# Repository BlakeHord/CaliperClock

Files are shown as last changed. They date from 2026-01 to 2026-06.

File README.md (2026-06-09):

# Caliper Clock

A low-power digital clock that uses the LCD salvaged from a cheap digital
caliper. The custom board drops into the caliper body, drives its 4-mux glass
directly, and is designed to operate for >1 year off a single 1.5V LR44 button cell.

Three major hardware revisions live in this repo.

## Revisions

| Dir | Board | Status |
|-----|---|---|
| [`Caliper_Clock_V1/`](Caliper_Clock_V1/) | ATtiny1616 + HT1621B LCD driver + RV-3028 RTC (incl. a test board) | original design |
| [`Caliper_Clock_V2/`](Caliper_Clock_V2/) | revised V1-class board **+ the working V2 firmware** | source of truth for the caliper LCD segment map & set-time UX. Battery depleted in days due to constant boost switching (wrong component choice) |
| [`Caliper_Clock_V3/`](Caliper_Clock_V3/) | **active redesign** around an **MSP430FR4133** (FRAM, integrated LCD_E + RTC, no HT1621) | hardware-verified, firmware **v1.0** running on the custom board |

**Active work is V3.** Its firmware ports the V2 segment map and time-setting
state machine onto the MSP430, displaying time on the real caliper glass via the
chip's built-in LCD controller and keeping time with the integrated RTC.

## V3 at a glance

- **MCU:** MSP430FR4133 (LCD_E drives the 4-mux caliper glass directly).
- **Power:** boosts a 1.5 V LR44 cell to 3.0 V (TPS61099); sleeps in LPM3 with
  the always-on LCD, targeting ~µA average for >year battery life.
- **Firmware:** `Caliper_Clock_V3/firmware/` — MSP430-GCC + `mspdebug`. The
  default build is the v1.0 product (full clock + buttons on the caliper glass);
  numbered diagnostic builds remain for bring-up. See its
  [README](Caliper_Clock_V3/firmware/README.md).
- **Hardware:** KiCad design, datasheets, and gerbers under `Caliper_Clock_V3/`.

```sh
cd Caliper_Clock_V3/firmware
make            # build v1.0 (the product)
make flash      # build + flash via the LaunchPad's eZ-FET (Spy-Bi-Wire)
```

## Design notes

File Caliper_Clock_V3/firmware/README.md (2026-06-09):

# Caliper Clock V3 Firmware

Firmware for the **MSP430FR4133IPM**-based Caliper Clock V3. Developed and tested
on an **MSP-EXP430FR4133 LaunchPad** while the custom boards are at the fab.

Toolchain: **MSP430-GCC** (compiler) + **mspdebug** with the **tilib** backend
(flashing over Spy-Bi-Wire via the LaunchPad's onboard eZ-FET). No CCS.

> Target platform for this setup: **macOS on Apple Silicon**. The clean path is
> MacPorts, because the `tilib` backend needs TI's proprietary `libmsp430.dylib`,
> which Homebrew core does not package. (Note: no live GDB on Apple Silicon —
> TI's debug-stack GDB path is x86_64 only. `mspdebug` still flashes fine.)

## Layout

```
firmware/
├── Makefile        # build / flash / debug / clean
├── src/            # .c sources (main.c = Task 1 blink stub for now)
├── inc/            # .h headers
├── build/          # object files        (git-ignored)
└── bin/            # firmware.elf output (git-ignored)
```

## One-time toolchain install (MacPorts)

1. Install MacPorts if you don't have it: https://www.macports.org/install.php
2. Install the compiler + flasher (pulls in support files, binutils, and the
   custom `libmsp430` port that provides the TI debug-stack dylib):

   ```sh
   sudo port install msp430-elf-gcc mspdebug
   ```

3. Verify the compiler is on PATH:

   ```sh
   msp430-elf-gcc --version
   ```

4. **Locate the device support files** (headers + linker script). The build
   needs `msp430fr4133.h` and `msp430fr4133.ld`:

   ```sh
   port contents msp430-gcc-support-files | grep -E 'msp430fr4133\.(h|ld)'
   ```

   - If they sit on the compiler's default search path, you're done.
   - Otherwise set `SUPPORT_DIR` to the directory containing them, either by
     editing the `Makefile` or per-invocation: `make SUPPORT_DIR=/path/to/include`.

## Build

```sh
make                 # builds the v1.0 PRODUCT (BRINGUP=7) -> bin/firmware.elf
make BRINGUP=1       # build a specific diagnostic instead (see below)
make clean           # removes build/ and bin/
```

The **default build is the product**: `BRINGUP=7`, the full clock on the caliper
glass (timekeeping + display + buttons), versioned `FW_VERSION` in the Makefile
(currently **v1.0**). The build prints a banner saying whether it produced the
product or a diagnostic.

`src/main.c` still selects the build at compile time via `BRINGUP`; the numbered
bring-up/diagnostic builds are kept in-tree and reachable with an override (e.g.
`make BRINGUP=3`). The object files don't track that flag, so **`make clean` when
switching `BRINGUP`**.

## Flash & debug (LaunchPad connected via USB)

```sh
make flash               # build + flash the v1.0 PRODUCT (BRINGUP=7)
make BRINGUP=1 flash     # build+flash a specific diagnostic instead
make debug               # interactive mspdebug session
```

The Makefile prefixes mspdebug with `DYLD_LIBRARY_PATH=/opt/local/lib` so `tilib`
can find `libmsp430.dylib`. If flashing fails to find the FET, unplug/replug the
LaunchPad and retry (a known macOS eZ-FET quirk).

## Bring-up sequence

Each step has a flashable test and a concrete "you should see X" so a failure
isolates to the layer just added — instead of debugging a whole clock at once.
Steps 1–6 verify on the LaunchPad; **step 7 is the v1.0 product** — the full
clock on the real caliper glass — and is now the default `make` build (it
requires a V3 board). The ladder is kept for diagnosing a regression to the
layer that introduced it.

| # | Build | What it proves | Pass criterion | Status |
|---|---|---|---|---|
| 1 | `make BRINGUP=1 flash` | Toolchain + flash path + chip alive | LaunchPad LED2 (P4.0) blinks ~1 Hz | ✓ |
| 2 | `make BRINGUP=2 flash` | LCD_E peripheral: 4-mux, charge-pump bias, ACLK, pin mux | LaunchPad glass shows **HELLO** | ✓ |
| 3 | `make BRINGUP=3 flash` (V3) | The V3→caliper SEG/COM map matches the physical glass | Scan test lights each (Lxx,COM) | ✓ (superseded by BRINGUP=14 slow scan) |
| 4 | `make BRINGUP=4 flash` | XT1 32.768 kHz + RTC 1 Hz tick | Time advances; LED2 toggles every 1 s | ✓ |
| 5 | `make BRINGUP=5 flash` | P1.0–1.2 wake from LPM3; 50 ms debounce | Button-to-GND shows MODE/HOUR/MIN | ✓ |
| 6 | `make BRINGUP=6 flash` | Full clock + set-time UI on LaunchPad | Time advances; long-press MODE → set; HOUR/MIN adjust; MODE commits | ✓ |
| 7 | `make flash` (default; V3) | **v1.0 product:** full clock on the caliper glass | 12:HH with blinking colon, battery icon as PM, buttons set time | ✓ verified on the custom V3 board (display + RTC + buttons) |
| — | power profiling | Meets the ~µA budget | LPM3 + LCD ≈ 1–2 µA on a meter / EnergyTrace | pending |

### Diagnostics (BRINGUP=8..17)

Kept in tree for re-running if the glass or PCB ever changes. These resolved the
V3 caliper LCD wiring empirically:

| Build | Purpose |
|---|---|
| `BRINGUP=8`  | Static "8888" on the caliper LCD (full digit + colon + PM lit) |
| `BRINGUP=9`  | Raw all-LCDM-bits-on (bypasses caliper helpers — probes hardware) |
| `BRINGUP=10..13` | Incremental: enable extra LCDPCTL bits, Mode 2 + VLCD_6, COM swap |
| `BRINGUP=14` | Slow per-(Lxx, COMy) scan, ~4 s/step — records empirical V3 segment map |
| `BRINGUP=15` | Static "1200" with colon bit toggled in SW every 3 s — isolates SEG_COLON path |
| `BRINGUP=16` | Light only the SEG_COLON candidate, alternating — confirms which physical segment a single bit drives |
| `BRINGUP=17` | Sweep V2 `(addr, com=3)` for addr=1..10, ~5 s each — locates icons/dots on the com 3 backplane |

Notes:
- **Step 2 caveat:** the FH-1138P glass on the LaunchPad has a *different* pinout
  from the caliper LCD. Step 2 only validates LCD_E itself; the caliper-specific
  segment map is Step 3.
- **Clock source:** Steps 1–2 run on the default post-reset ACLK (~32 kHz REFO).
  Step 4 switches ACLK to the 32.768 kHz **XT1** crystal for accuracy.
- **Sleep mode = LPM3, not LPM3.5.** Per §8.7, LPM3 with the LCD and RTC is
  ~1.1 µA typ; the always-on LCD charge pump dominates the budget, so LPM3.5
  would save only ~0.2 µA at the cost of waking via reset.
- **LaunchPad gotcha:** **pull jumper JP1 (LED1)** for button tests. JP1 puts
  the green LED in series with P1.0 to GND, pulling P1.0 to ~1.8 V and breaking
  the MODE button.

## Status (current)

All seven tasks are implemented and verified on hardware (V3 board for caliper
LCD, buttons, RTC; LaunchPad for LCD_E peripheral check). Outstanding:

- **Task 7 power profiling** — code is at low-power defaults; current draw not
  yet measured. The charge-pump frequency was bumped to *fastest* (`LCDCPFSELx
  = 0`) to fix faint contrast on the caliper glass; this raises LPM3+LCD above
  the §8.7 ~1.07 µA typ. See "Power profiling" below.
- **AM/PM in set-mode** — currently not toggled while setting (mirrors V2).
  Open product question, not a bug.
- **Display refresh artifact** — `caliper_lcd_show_4digit` does `clear()` then
  re-writes the digit bits; byte 6 briefly transitions through 0 each tick,
  visible as a ~1 Hz "glitch" of the whole display. Cosmetic; mitigated by
  computing the new byte values and writing them in one assignment instead of
  clear-then-OR.
- **"in" icon ties to the decimal** — at L16 com 3 the LCD glass shares a trace
  between the decimal dot and the "in" indicator, so they blink together. Not
  separable in software (hardware-tied). Accepted.

### V3 caliper LCD wiring (resolved Jun 2026)

Same physical glass as V2, so V2's `DIGIT_SEG`, `SEG_COLON = (8, 3)`, and
`SEG_PM = (3, 3)` all carry over. The V2→V3 translation needed two fixes
documented in `caliper_lcd.c` and `CLAUDE.md`:

- `HT1621_ADDR_TO_LCDE_SEG`: V2 addr N → V3 L(N+8) for N=1..10 (was earlier
  guessed as L(N+7) with addr 10→L18; L17 is **not** NC, it carries V2 addr 9).
- `LCDM0W = 0x1248`: L0↔L3 *and* L1↔L2 swapped vs. default — V2 com 1 and com 2
  both need swapping on this board, not just com 3 via L0↔L3.

## Power profiling (Task 7)

The goal is ~3 µA average for 1.5–3 yr on an LR44/SR44. This is an on-hardware
measurement; the firmware is already written to hit it (LPM3, XT1 ACLK, all
unused pins driven low). What's left is to confirm and chase any leaks.

**Targets** (datasheet §8.7, 3 V typ): LPM3 + LCD + charge pump ≈ **1.07 µA**;
LPM3 + RTC ≈ 1.08 µA. The always-on LCD charge pump dominates the budget.

**How to measure**
- Easiest: the LaunchPad's onboard **EnergyTrace** (CCS/UniFlash) — but note its
  floor (~hundreds of nA) and that LaunchPad LEDs/jumpers add current; pull the
  `LED`/`RXD`/`TXD` jumpers on J101.
- Most accurate: a µA meter (or DMM in µA range) in series with the coin cell on
  the V3 board, MCU sleeping in LPM3.

**Procedure**
1. Flash a steady-state build and let it idle in LPM3 (no buttons pressed).
2. Read the average current; expect ≈ 1–2 µA. The per-second RTC wake is too
   brief to matter to the average.
3. Press a button and confirm the wake spike is short (< ~10 ms) before it
   returns to LPM3.

**If it's over budget, check (in order)**
- **LCD charge-pump frequency:** currently `LCDCPFSELx = 0` (fastest, *max*
  contrast and *max* current). Original bootstrap target was `LCDCPFSELx = 0xF`
  (slowest) for §8.7 ~1.07 µA, but that put V3's caliper glass at threshold.
  Sweep upward incrementally (1, 3, 7, …, 0xF) until contrast just degrades,
  then back off one step — that's the right tradeoff.
- Floating inputs: every unused pin should be output-low (`board_init()` does
  this; verify nothing re-floats a pin).
- DCO/FLL/REFO left running: should be off in LPM3 (ACLK is XT1). REFO is only
  requested by the FLL during brief active wakes.
- SVS: excluded from the datasheet typicals above; disable if enabled and not
  needed.
- XT1 drive: after startup the drive strength can be reduced (CSCTL6 XT1DRIVE)
  once oscillation is reliable.

## Next steps

In rough priority order:

1. **Timekeeping accuracy on the V3 board.** v1.0 (`make flash`) runs on the
   custom board with display + buttons verified, but the V3 board has its own
   FC-135 XT1 crystal (RTCMOD=31 was tuned on the LaunchPad). **Action:** let it
   run several hours against a reference clock; if it drifts, re-check XT1 load
   caps and RTCMOD.
2. **Power measurement (Task 7).** µA meter in series with VDD on the V3 board,
   MCU sleeping in LPM3. Record baseline, then sweep `LCDCPFSELx` from 0 toward
   0xF and find the lowest setting that keeps segments legible — that's the
   power/contrast operating point.
3. **Display refresh artifact.** The ~1 Hz "glitch" comes from
   `caliper_lcd_show_4digit` clearing bytes 4–9 then re-writing. Replace with a
   compute-locally-then-store-once pattern so segment bytes change in a single
   write per byte, no visible blank step.
4. **AM/PM in set-mode** (product decision). Add a fourth set-mode state that
   toggles PM, or accept V2's behaviour of "set the digits, AM/PM derives from
   24 h rollover."
5. **LPM3.5 (only if power budget fails).** Requires FRAM persistence of the
   clock state + full re-init on every wake. Saves ~0.2 µA over LPM3 with the
   LCD charge pump dominating, so not worth the complexity unless measurement
   forces it.

## References

Datasheets live in `../Datasheets/` (msp430fr4133, slau445 family UG, slaa654
LCD_E app note, tps61099, ht1621b, slau595 LaunchPad UG). The V2 firmware with the
hard-won caliper LCD segment map is in `../../Caliper_Clock_V2/main.c`.

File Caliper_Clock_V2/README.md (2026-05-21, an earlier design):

# Caliper Clock

A low-power digital clock built using a salvaged LCD display from a digital caliper, driven by an ATtiny1616 microcontroller with an RV-3028 real-time clock.

 

## Features

- **Ultra-low power consumption** — ATtiny1616 sleeps in power-down mode, waking only on RTC minute interrupts
- **12-hour time display** with AM/PM indicator and blinking colon
- **Button-based time setting** — long-press to enter setting mode, adjust hours/minutes with dedicated buttons
- **Accurate timekeeping** — RV-3028 RTC with minute-update interrupt
- **Repurposed LCD** — uses an HT1621B-compatible LCD from a digital caliper (4-digit 7-segment display)

## Hardware

### Components

| Component | Description |
|---|---|
| ATtiny1616 | 8-bit AVR microcontroller, 20 MHz, 20 pins, supports sleep modes, GPIO, interrupts |
| HT1621B | 32-nibble LCD driver, 4-com 1/3-bias, SPI/parallel interface |
| RV-3028 | I2C RTC, 24-hour mode, minute alarm output, ultra-low-power |
| AP3015AKTR-G1 | Boost Switching Regulator IC |

### Pin Mapping

#### LCD (HT1621B)
| Signal | Pin |
|---|-----|
| DATA | PA1 |
| WR | PA7 |
| /CS | PB3 |

#### RTC (RV-3028 via Soft I²C)
| Signal | Pin |
|---|-----|
| SDA | PA2 |
| SCL | PA3 |
| INT | PA4 |

#### Buttons
| Function | Pin |
|---|-----|
| Mode | PB0 |
| Hour+ | PB1 |
| Minute+  | PB2 |

#### Debug
| Function | Pin |
|---|-----|
| LED | PA6 |

## PCB Designs

The repository is organized into one folder per board revision:

- **Caliper_Clock_V1/** — Original board (includes the `Caliper_Clock_Test_Board/` test/development board)
- **Caliper_Clock_V2/** — Revised board design (also contains this firmware and tooling)
- **Caliper_Clock_V3/** — MSP430FR4133-based redesign (includes the `MSP430FR4133IPM/` symbol library)

Each folder contains:
- KiCad schematic (`.kicad_sch`)
- KiCad PCB layout (`.kicad_pcb`)
- Gerber files for manufacturing
- BOM and pick-and-place files

## Building the Firmware

### Prerequisites

- AVR-GCC toolchain (avr-gcc 14 recommended)
- avr-objcopy

On macOS with Homebrew:
```bash
brew install avr-gcc@14
```

### Compile

```bash
make clean
make
```

This produces `blink.hex` ready for flashing.

### Flash

Use a UPDI programmer (e.g., SerialUPDI, Atmel-ICE, or jtag2updi):

```bash
# Example with pymcuprog
pymcuprog write -t uart -u /dev/tty.usbserial-XXXX -d attiny1616 -f blink.hex
```

## Usage

### Normal Operation

- The clock displays time in 12-hour format with AM/PM indicator
- Colon blinks at ~1 Hz
- MCU sleeps between updates for minimal power consumption

### Setting the Time

1. **Long-press the Mode button (PB0)** for ~5 seconds to enter time-setting mode
2. Display will flash to indicate setting mode
3. **Press Hour button (PB1)** to increment hours (1-12)
4. **Press Minute button (PB2)** to increment minutes (0-59)
5. **Press Mode button (PB0)** again to save and exit

Hold Hour or Minute buttons for auto-repeat.

## Firmware Variants

The repository includes several firmware versions:

| File | Description |
|---|---|
| `main.c` | Current version with low-power mode and button time-setting |
| `main-CLOCK-V1.c` | Earlier clock implementation |
| `main-BASIC-CLOCK.c` | Basic clock without power optimization |
| `main-RTC-test.c` | RTC testing/debugging |
| `main-lcd_count.c` | LCD counting test |
| `main-lcd_walk.c` | LCD segment walking test |
| `main-blink_WR_CS_LED.c` | GPIO/LED blink test |

## Python Utilities

- **lcd_driver.py** — ESP32 MicroPython LCD driver (for prototyping)
- **lcd_screen_decoding.py** — LCD segment mapping analysis tool

## License

MIT License — feel free to use, modify, and share!

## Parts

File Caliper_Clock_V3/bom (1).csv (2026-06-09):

Comment | Designator | Footprint | LCSC Part #
10uF | C1,C2,C3 | C_0805_2012Metric | C15850
100nF | C4,C7 | C_0402_1005Metric | C1525
1nF | C5 | C_0402_1005Metric | C1523
12pF | CX1,CX2 | C_0402_1005Metric | C1547
2.0M | R1 | R_0402_1005Metric | C11512
1.0M | R2 | R_0402_1005Metric | C26083
47k | R3 | R_0402_1005Metric | C25792
2.2uH | L1 | L_0805_2012Metric | C41651
32.768kHz | Y1 | Crystal_SMD_3215-2Pin_3.2x1.5mm | C32346
TPS61099DRVR | U1 | WSON-6-1EP_2x2mm_P0.65mm_EP1x1.6mm | C2842395
MSP430FR4133IPM | U2 | PM0064A_N | C106759
MY-ZJ-117 | CL_1 | MY-ZJ-117 | C964865
MY-FJ-118 | CL_2 | MY-FJ-118 | C964866

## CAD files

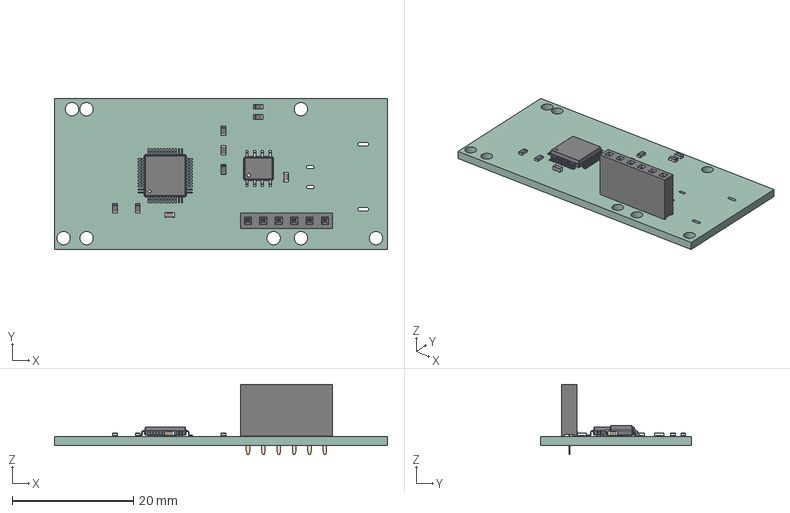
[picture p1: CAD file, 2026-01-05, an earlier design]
Caliper_Clock_V1/Caliper_Clock.step
55.0 x 25.0 x 11.6 mm
R_0603_1608Metric x 7
PinSocket_1x06_P2.54mm_Vertical
C_0603_1608Metric x 2
LQFP-48_7x7mm_P0.5mm
SOIC-8_3.9x4.9mm_P1.27mm
Caliper_Clock_PCB

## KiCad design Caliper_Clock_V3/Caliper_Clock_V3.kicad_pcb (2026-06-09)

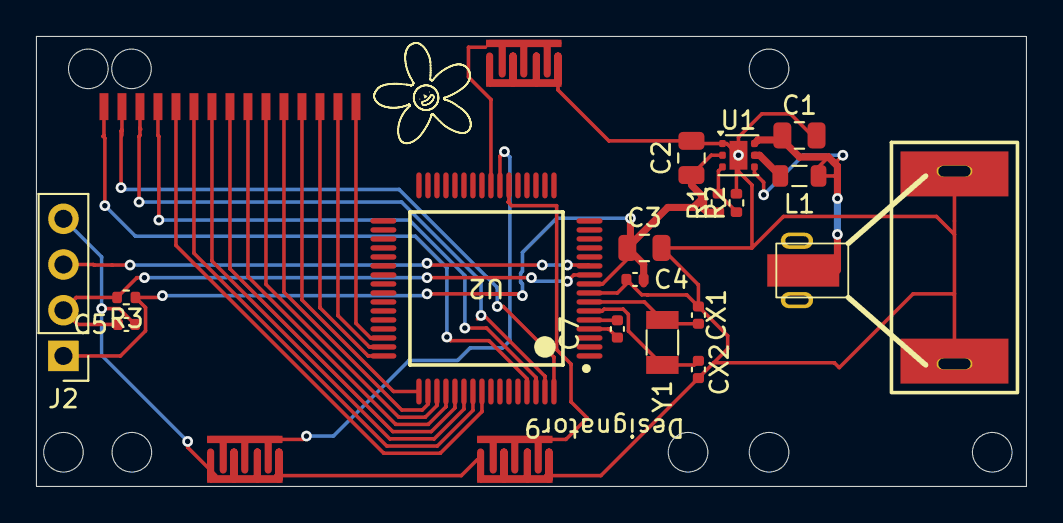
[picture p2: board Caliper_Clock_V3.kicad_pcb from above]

Board: 2 copper layers, 55.0 x 25.0 mm, 22 parts (0 on the bottom side), 29 nets.

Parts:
C1, C2, C3: 10uF; C_0805_2012Metric
C4, C7: 100nF; C_0402_1005Metric
C5: 1nF; C_0402_1005Metric
CL_1: MY-ZJ-117
CL_2: MY-ZJ-118
CX1, CX2: 12pF; C_0402_1005Metric
J1: LCD PADS
J2: SBW; PinHeader_1x04_P2.54mm_Vertical
L1: 2.2uH; L_0805_2012Metric
R1: 2.0M; R_0402_1005Metric
R2: 1.0M; R_0402_1005Metric
R3: 47k; R_0402_1005Metric
SW1: MODE; Button_trace_caliper_board
SW2: HOUR; Button_trace_caliper_board
SW3: MIN; Button_trace_caliper_board
U1: TPS61099DRVR; WSON-6-1EP_2x2mm_P0.65mm_EP1x1.6mm
U2: MSP430FR4133IPM; PM0064A_N
Y1: 32.768kHz; Crystal_SMD_3215-2Pin_3.2x1.5mm

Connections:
+3V0: C2.1, C3.1, C4.1, J2.1, R1.1, R3.1, U1.2 (VOUT), U2.9 (DVCC)
+BATT: C1.1, L1.1, U1.4 (EN), U1.6 (VIN)
/BTN_HOUR: SW2.1, U2.23 (P1.1_UCA0RXD_UCA0SOMI_A1_Veref+)
/BTN_MIN: SW3.1, U2.22 (P1.2_UCA0CLK_A2)
/BTN_MODE: SW1.1, U2.24 (P1.0_UCA0TXD_UCA0SIMO_A0_Veref-)
/LCD_COM0: J1.2, U2.64 (P7.0_L0)
/LCD_COM1: J1.3, U2.63 (P7.1_L1)
/LCD_COM2: J1.4, U2.62 (P7.2_L2)
/LCD_COM3: J1.1, U2.61 (P7.3_L3)
/LCD_SEG0: J1.5, U2.56 (P3.0_L8)
/LCD_SEG1: J1.6, U2.55 (P3.1_L9)
/LCD_SEG2: J1.7, U2.54 (P3.2_L10)
/LCD_SEG3: J1.8, U2.53 (P3.3_L11)
/LCD_SEG4: J1.9, U2.52 (P3.4_L12)
/LCD_SEG5: J1.10, U2.51 (P3.5_L13)
/LCD_SEG6: J1.11, U2.50 (P3.6_L14)
/LCD_SEG7: J1.12, U2.49 (P3.7_L15)
/LCD_SEG8: J1.13, U2.48 (P6.0_L16)
/LCD_SEG9: J1.14, U2.47 (P6.1_L17)
/LCD_SEG10: J1.15, U2.46 (P6.2_L18)
/RST_n: C5.1, J2.2, R3.2, U2.10 (RST_NMI_SBWTDIO_N)
/TEST_SBWTCK: J2.3, U2.11 (TEST_SBWTCK)
/XIN: CX1.1, U2.7 (P4.1_XIN), Y1.1
/XOUT: CX2.1, U2.6 (P4.2_XOUT), Y1.2
GND: C1.2, C2.2, C3.2, C4.2, C5.2, CX1.2, CX2.2, J2.4, R2.2, SW1.2, SW2.2, SW3.2, U1.1 (GND), U1.7 (PAD/GND), U2.8 (DVSS)
unnamed: R1.2, R2.1, U1.3 (FB)
unnamed: L1.2, U1.5 (SW)
unnamed: C7.2, U2.5 (P4.3_LCDCAP0)
unnamed: C7.1, U2.4 (P4.4_LCDCAP1)

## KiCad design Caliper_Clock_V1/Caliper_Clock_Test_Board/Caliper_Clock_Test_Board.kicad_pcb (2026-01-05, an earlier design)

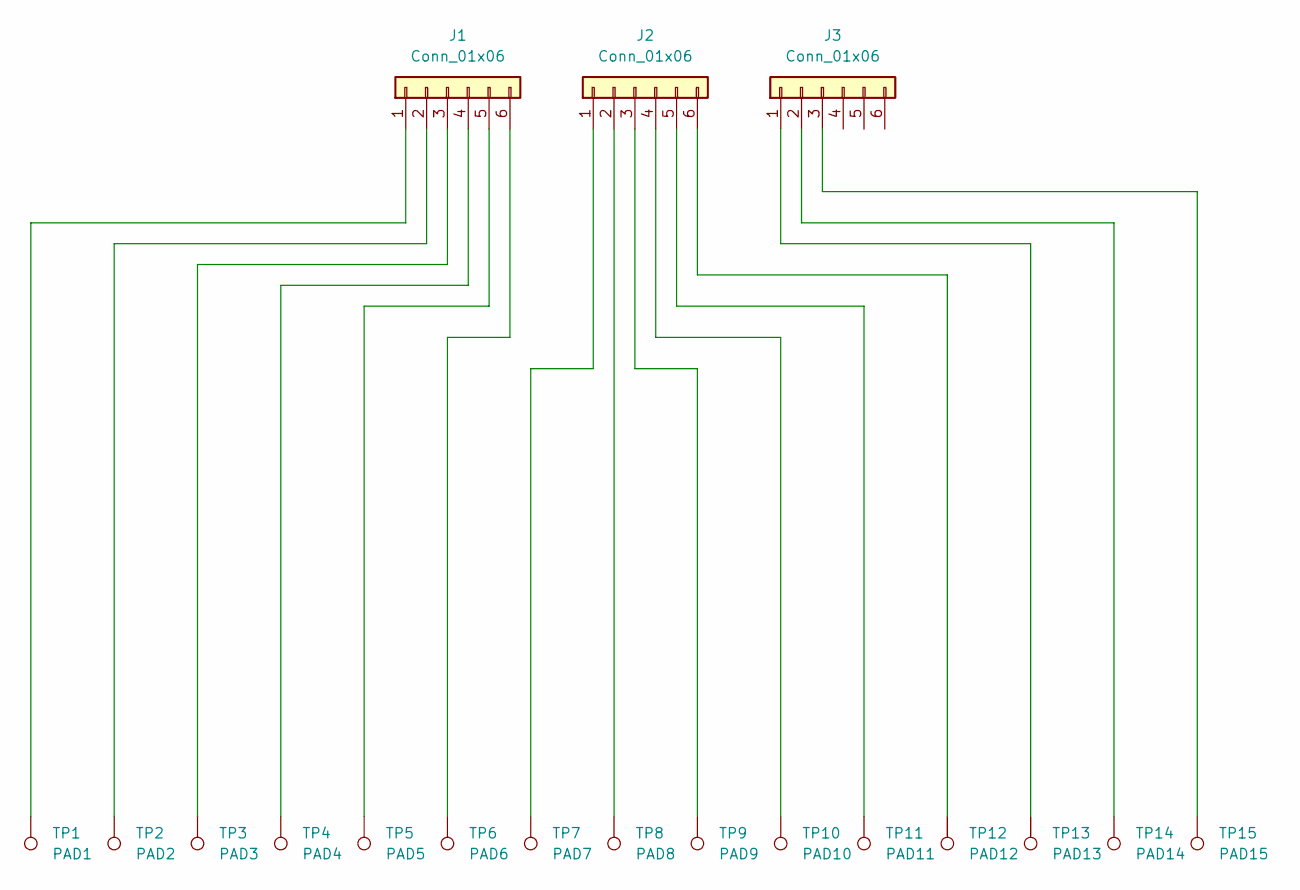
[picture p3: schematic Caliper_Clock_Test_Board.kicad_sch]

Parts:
J1, J2, J3: Conn_01x06; PinSocket_1x06_P2.54mm_Vertical
TP1: PAD1; TestPoint_Pad_0.5mm_x_5.0mm
TP2: PAD2; TestPoint_Pad_0.5mm_x_5.0mm
TP3: PAD3; TestPoint_Pad_0.5mm_x_5.0mm
TP4: PAD4; TestPoint_Pad_0.5mm_x_5.0mm
TP5: PAD5; TestPoint_Pad_0.5mm_x_5.0mm
TP6: PAD6; TestPoint_Pad_0.5mm_x_5.0mm
TP7: PAD7; TestPoint_Pad_0.5mm_x_5.0mm
TP8: PAD8; TestPoint_Pad_0.5mm_x_5.0mm
TP9: PAD9; TestPoint_Pad_0.5mm_x_5.0mm
TP10: PAD10; TestPoint_Pad_0.5mm_x_5.0mm
TP11: PAD11; TestPoint_Pad_0.5mm_x_5.0mm
TP12: PAD12; TestPoint_Pad_0.5mm_x_5.0mm
TP13: PAD13; TestPoint_Pad_0.5mm_x_5.0mm
TP14: PAD14; TestPoint_Pad_0.5mm_x_5.0mm
TP15: PAD15; TestPoint_Pad_0.5mm_x_5.0mm

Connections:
unnamed: J1.1, TP1.1
unnamed: J1.2, TP2.1
unnamed: J1.3, TP3.1
unnamed: J1.4, TP4.1
unnamed: J1.5, TP5.1
unnamed: J1.6, TP6.1
unnamed: J2.1, TP7.1
unnamed: J2.2, TP8.1
unnamed: J2.3, TP9.1
unnamed: J2.4, TP10.1
unnamed: J2.5, TP11.1
unnamed: J2.6, TP12.1
unnamed: J3.1, TP13.1
unnamed: J3.2, TP14.1
unnamed: J3.3, TP15.1

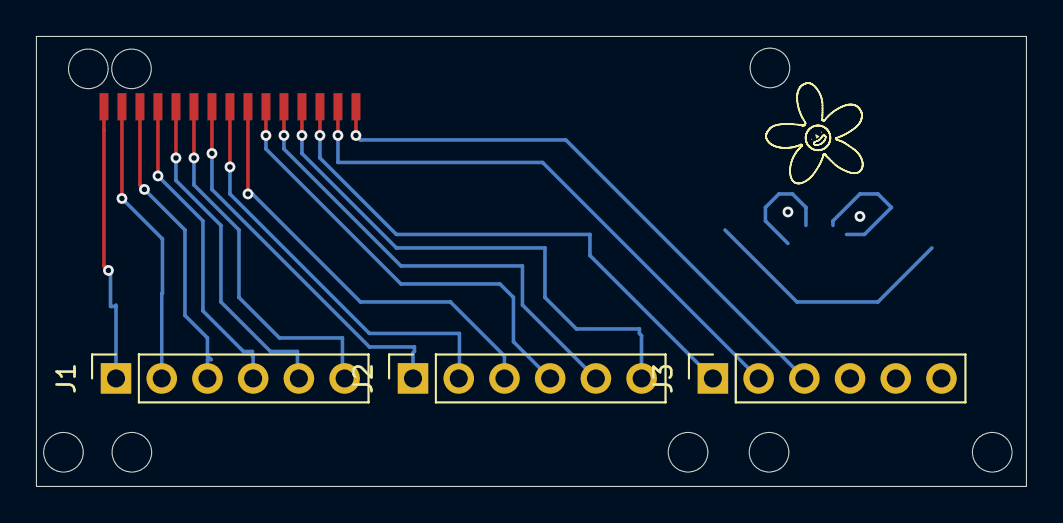
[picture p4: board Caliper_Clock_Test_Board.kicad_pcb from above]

Board: 2 copper layers, 55.0 x 25.0 mm, 18 parts (0 on the bottom side), 15 nets.

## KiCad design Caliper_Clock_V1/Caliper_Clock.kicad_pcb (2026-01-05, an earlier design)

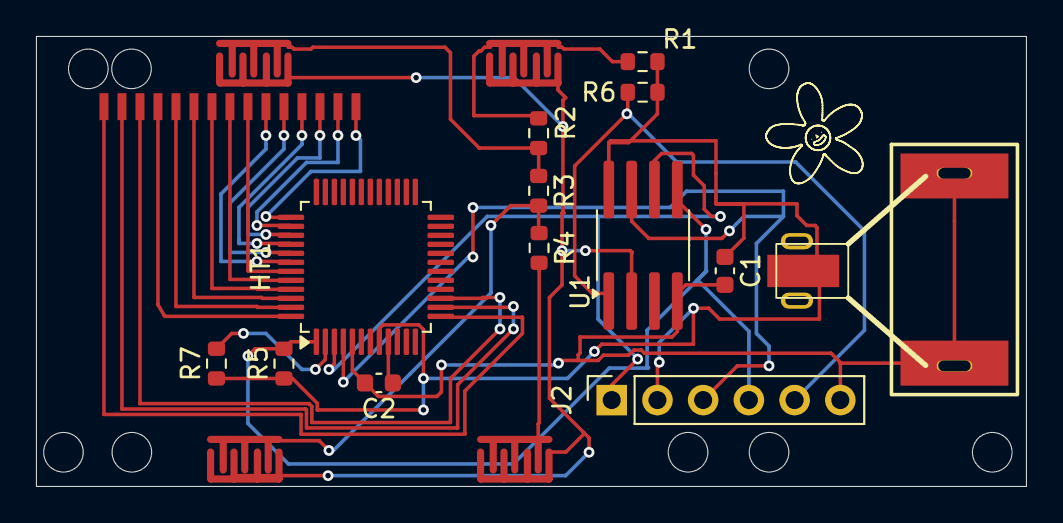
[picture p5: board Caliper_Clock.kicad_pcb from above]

Board: 2 copper layers, 55.0 x 25.0 mm, 33 parts (0 on the bottom side), 24 nets.

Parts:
C1, C2: C100n; C_0603_1608Metric
CL_1: MY-ZJ-117
CL_2: MY-ZJ-118
HT1: LQFP-48_7x7mm_P0.5mm
J2: Conn_01x06; PinSocket_1x06_P2.54mm_Vertical
R1, R6: R10k; R_0603_1608Metric
R2: R20k; R_0603_1608Metric
R3: R30k; R_0603_1608Metric
R4: R40k; R_0603_1608Metric
R5, R7: R4.7k; R_0603_1608Metric
TP1: PAD1; TestPoint_Pad_0.5mm_x_5.0mm
TP2: PAD2; TestPoint_Pad_0.5mm_x_5.0mm
TP3: PAD3; TestPoint_Pad_0.5mm_x_5.0mm
TP4: PAD4; TestPoint_Pad_0.5mm_x_5.0mm
TP5: PAD5; TestPoint_Pad_0.5mm_x_5.0mm
TP6: PAD6; TestPoint_Pad_0.5mm_x_5.0mm
TP7: PAD7; TestPoint_Pad_0.5mm_x_5.0mm
TP8: PAD8; TestPoint_Pad_0.5mm_x_5.0mm
TP9: PAD9; TestPoint_Pad_0.5mm_x_5.0mm
TP10: PAD10; TestPoint_Pad_0.5mm_x_5.0mm
TP11: PAD11; TestPoint_Pad_0.5mm_x_5.0mm
TP12: PAD12; TestPoint_Pad_0.5mm_x_5.0mm
TP13: PAD13; TestPoint_Pad_0.5mm_x_5.0mm
TP14: PAD14; TestPoint_Pad_0.5mm_x_5.0mm
TP15: PAD15; TestPoint_Pad_0.5mm_x_5.0mm
TP16: BTN1; Button_trace_caliper_board
TP17: BTN2; Button_trace_caliper_board
TP18: BTN3; Button_trace_caliper_board
TP19: BTN4; Button_trace_caliper_board
U1: ATtiny85-20M; SOIC-8_3.9x4.9mm_P1.27mm

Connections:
GND: C1.2, C2.2, HT1.5 (VSS), J2.6, U1.4 (GND)
unnamed: HT1.13 (COM0), TP1.1
unnamed: HT1.14 (COM1), TP2.1
unnamed: HT1.15 (COM2), TP3.1
unnamed: HT1.1 (CS), J2.4, R5.2, U1.5 (AREF/PB0)
unnamed: HT1.4 (DATA), J2.3, U1.7 (PB2)
unnamed: HT1.2 (RD), R7.2
unnamed: HT1.48 (SEG0), TP4.1
unnamed: HT1.47 (SEG1), TP5.1
unnamed: HT1.46 (SEG2), TP6.1
unnamed: HT1.45 (SEG3), TP7.1
unnamed: HT1.44 (SEG4), TP8.1
unnamed: HT1.43 (SEG5), TP9.1
unnamed: HT1.42 (SEG6), TP10.1
unnamed: HT1.41 (SEG7), TP11.1
unnamed: HT1.40 (SEG8), TP12.1
unnamed: HT1.39 (SEG9), TP13.1
unnamed: HT1.38 (SEG10), TP14.1
unnamed: HT1.37 (SEG11), TP15.1
unnamed: C2.1, HT1.9 (VDD)
unnamed: HT1.3 (WR), J2.1, U1.6 (PB1)
unnamed: J2.5, R6.2, U1.1 (~RESET/PB5)
unnamed: R1.2, R2.1, R2.2, R3.1, R3.2, R4.1, R4.2, U1.2 (XTAL1/PB3)
VCC: C1.1, HT1.8 (VLCD), J2.2, R1.1, R5.1, R6.1, R7.1, U1.8 (VCC)

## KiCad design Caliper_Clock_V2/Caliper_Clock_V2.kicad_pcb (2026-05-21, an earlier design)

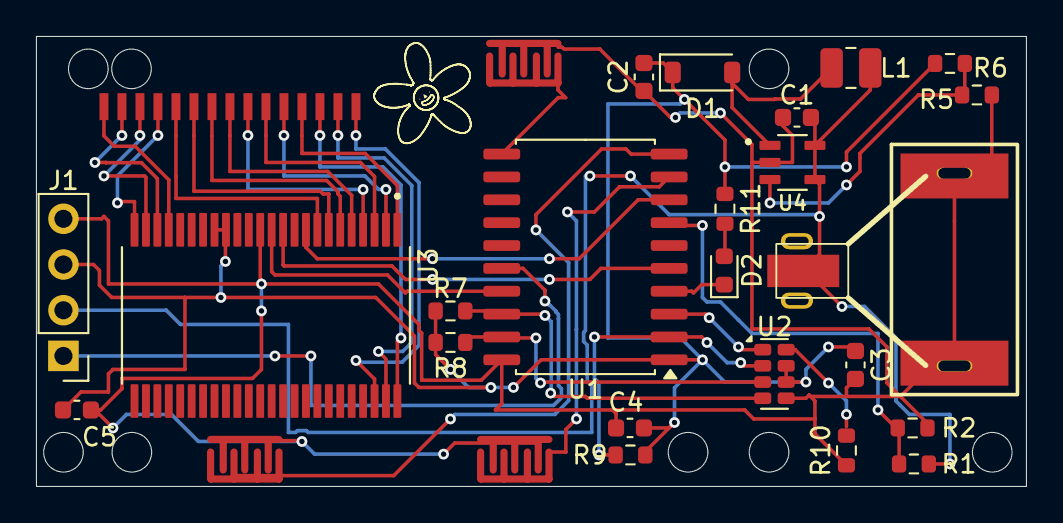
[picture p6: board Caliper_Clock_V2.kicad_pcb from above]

Board: 2 copper layers, 55.0 x 25.0 mm, 42 parts (0 on the bottom side), 32 nets.

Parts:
C1: 10uF; C_0603_1608Metric
C2: 22uF; C_0603_1608Metric
C3, C4, C5: 0.1uF; C_0603_1608Metric
CL_1: MY-ZJ-117
CL_2: MY-ZJ-118
D1: MBR0540; D_SOD-123
D2: LED; D_0603_1608Metric
J1: Conn_01x04; PinHeader_1x04_P2.54mm_Vertical
L1: 10uH; L_1008_2520Metric
R1: 2.2M; R_0603_1608Metric
R2: 1.0M; R_0603_1608Metric
R5: 1.43M; R_0603_1608Metric
R6: 1.00M; R_0603_1608Metric
R7, R8: 10k; R_0603_1608Metric
R9: 47k; R_0603_1608Metric
R10: 100k; R_0603_1608Metric
R11: 1.1k; R_0603_1608Metric
TP1: PAD1; TestPoint_Pad_0.5mm_x_5.0mm
TP2: PAD2; TestPoint_Pad_0.5mm_x_5.0mm
TP3: PAD3; TestPoint_Pad_0.5mm_x_5.0mm
TP4: PAD4; TestPoint_Pad_0.5mm_x_5.0mm
TP5: PAD5; TestPoint_Pad_0.5mm_x_5.0mm
TP6: PAD6; TestPoint_Pad_0.5mm_x_5.0mm
TP7: PAD7; TestPoint_Pad_0.5mm_x_5.0mm
TP8: PAD8; TestPoint_Pad_0.5mm_x_5.0mm
TP9: PAD9; TestPoint_Pad_0.5mm_x_5.0mm
TP10: PAD10; TestPoint_Pad_0.5mm_x_5.0mm
TP11: PAD11; TestPoint_Pad_0.5mm_x_5.0mm
TP12: PAD12; TestPoint_Pad_0.5mm_x_5.0mm
TP13: PAD13; TestPoint_Pad_0.5mm_x_5.0mm
TP14: PAD14; TestPoint_Pad_0.5mm_x_5.0mm
TP15: PAD15; TestPoint_Pad_0.5mm_x_5.0mm
TP17: BTN2; Button_trace_caliper_board
TP18: BTN3; Button_trace_caliper_board
TP19: BTN4; Button_trace_caliper_board
U1: ATtiny1616-S; SOIC-20W_7.5x12.8mm_P1.27mm
U2: RV-3028-C7; MicroCrystal_C7_SON-8_1.5x3.2mm_P0.9mm
U3: HT1621B; SOP63P1035X279-48N
U4: AP3015AKTR-G1; SOT95P280X145-5N

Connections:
+1V5: C1.1, CL_1.3, J1.2, L1.2, R1.2, U4.4 (~SHDN), U4.5 (VIN)
+3V0: C2.2, C3.1, C4.2, C5.1, D1.1 (K), J1.3, R5.2, R7.2, R8.2, R9.2, R11.1, U1.1 (VCC), U2.6 (VBACKUP), U2.7 (VDD), U3.16 (VLCD), U3.17 (VDD)
/BAT_SENSE: R1.1, R2.2, U1.7 (PB4)
/CLKOUT: U1.3 (PA5), U2.1 (CLKOUT)
/COM0: TP1.1, U3.21 (COM0)
/COM1: TP2.1, U3.22 (COM1)
/COM2: TP3.1, U3.23 (COM2)
/COM3: TP4.1, U3.24 (COM3)
/INT: R9.1, U1.2 (PA4), U2.2 (~INT)
/LCD_CS: U1.8 (PB3), U3.9 (~CS)
/LCD_DATA: U1.17 (PA1), U3.12 (DATA)
/LCD_WR: U1.5 (PA7), U3.11 (~WR)
/SCL: R8.1, U1.19 (PA3), U2.3 (SCL)
/SDA: R7.1, U1.18 (PA2), U2.4 (SDA)
/UPDI: J1.1, U1.16 (~RESET/PA0)
GND: C1.2, C2.1, C3.2, C4.1, C5.2, CL_2.1, CL_2.2, J1.4, R2.1, R6.2, R10.1, U1.9 (PB2), U1.10 (PB1), U1.11 (PB0), U1.20 (GND), U2.5 (VSS), U3.13 (VSS), U4.2 (GND)
unnamed: D1.2 (A), L1.1, U4.1 (SW)
unnamed: D2.2 (A), R11.2
unnamed: D2.1 (K), U1.4 (PA6)
unnamed: R10.2, U2.8 (EVI)
unnamed: TP5.1, U3.8 (SEG0)
unnamed: TP6.1, U3.7 (SEG1)
unnamed: TP7.1, U3.6 (SEG2)
unnamed: TP8.1, U3.5 (SEG3)
unnamed: TP9.1, U3.4 (SEG4)
unnamed: TP10.1, U3.3 (SEG5)
unnamed: TP11.1, U3.2 (SEG6)
unnamed: TP12.1, U3.1 (SEG7)
unnamed: TP13.1, U3.48 (SEG8)
unnamed: TP14.1, U3.47 (SEG9)
unnamed: TP15.1, U3.46 (SEG10)
unnamed: R5.1, R6.1, U4.3 (FB)

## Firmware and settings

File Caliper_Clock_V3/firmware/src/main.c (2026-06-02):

/*
 * Caliper Clock V3 -- bring-up entry point.
 *
 * Selects one bring-up test at compile time so each layer can be flashed and
 * verified on its own (see README "Bring-up sequence"):
 *
 *   make BRINGUP=1 flash   -> Task 1: blink LaunchPad LED2 (toolchain check)
 *   make BRINGUP=2 flash   -> Task 2: LCD_E displays "HELLO" on the LaunchPad
 *   make BRINGUP=3 flash   -> Task 3: caliper LCD segment scan (V3 board only)
 *   make BRINGUP=4 flash   -> Task 4: XT1+RTC timekeeping demo on the LaunchPad
 *   make BRINGUP=5 flash   -> Task 5: buttons + LPM3 wake (P1.0-1.2 to GND)
 *   make BRINGUP=6 flash   -> Task 6: full clock + set-time UI on the LaunchPad
 *   make BRINGUP=7 flash   -> V3 final: full clock + set-time on the caliper LCD
 *   make BRINGUP=8 flash   -> diagnostic: caliper LCD statically shows "8888"
 *                            (every segment of every digit + colon + PM)
 *   make BRINGUP=9 flash   -> diagnostic: light EVERY LCD memory bit raw
 *                            (no V2 map, no caliper_lcd helpers -- proves
 *                             whether COM3 + L17 hardware actually works)
 *   make BRINGUP=10 flash  -> diagnostic: show_4digit + enable L18/L19 as LCD pins
 *                            (isolates whether enabling extra LCDPCTL bits is what
 *                             made BRINGUP=9 work, vs. the actual byte-9 writes)
 *   make BRINGUP=11 flash  -> diagnostic: show_4digit + LCDPCTL1 + write byte 9 = 0xFF
 *                            (isolates whether driving L18/L19 is what fixes things)
 *   make BRINGUP=12 flash  -> diagnostic: as BRINGUP=11 but with Mode 2 + VLCD_6
 *                            (test if charge pump needs an explicit VLCDx > 0)
 *   make BRINGUP=13 flash  -> diagnostic: as BRINGUP=11 + COM swap LCDM0W=0x1428
 *                            (swaps L0<->L3 COM assignment so firmware "COM3"
 *                             phase comes out on L0 = J1.2 = V2's actual COM3
 *                             backplane on the caliper LCD)
 *   make BRINGUP=14 flash  -> diagnostic: slow per-(Lxx,COMy) scan (~4 s each).
 *                            Records empirical (Lxx, COMy) -> physical caliper
 *                            segment map for rebuilding the V2->V3 translation.
 *                            Cycle starts: all-on 4 s + all-dark 4 s, then
 *                            L8 com0, L8 com1, ..., L18 com3 (44 steps).
 *   make BRINGUP=15 flash  -> diagnostic: static "1200" with the colon bit
 *                            alternated on/off every 3 s by software (no RTC).
 *                            Isolates the SEG_COLON write path: if the decimal
 *                            blinks here, BRINGUP=7's "no-blink" is upstream.
 *   make BRINGUP=16 flash  -> diagnostic: ONLY the SEG_COLON candidate (V2 5,3)
 *                            is lit, nothing else, toggled every 4 s. Pin down
 *                            which physical element the SEG_COLON write hits.
 *   make BRINGUP=17 flash  -> diagnostic: walks V2 (addr, com=3) for addr=1..10,
 *                            ~5 s per step, nothing else lit. Note which addr's
 *                            step lights the decimal between D2 and D1. Cycle
 *                            marker = 5 s blank between sweeps.
 *
 * Higher tasks (RTC, buttons, LPM3.5, set-time, the real caliper LCD) get added
 * as they're implemented. BRINGUP defaults to the highest test in the Makefile.
 */

#include <msp430.h>

#ifndef BRINGUP
#define BRINGUP 2
#endif

/* Common board init: stop watchdog, drive all GPIO low to minimize leakage,
 * then release the power-up high-Z state.
 *
 * Driving every pin as an output low is TI's recommended treatment for unused
 * pins (datasheet SLAS865 §7.4 "Connection of Unused Pins"); each module's init
 * then reclaims the specific pins it needs (LCD via LCDPCTL, XT1 via P4SEL0,
 * buttons as inputs). LOCKLPM5 must be cleared for the I/O config to take effect
 * (FR4xx LPMx.5 lock; SLAU445 Digital I/O). The FR4133 exposes GPIO as 16-bit
 * port pairs PA=P1:P2, PB=P3:P4, PC=P5:P6, PD=P7:P8. */
static void board_init(void)
{
    WDTCTL = WDTPW | WDTHOLD;

    PADIR = 0xFFFF; PAOUT = 0x0000;   /* P1, P2 */
    PBDIR = 0xFFFF; PBOUT = 0x0000;   /* P3, P4 */
    PCDIR = 0xFFFF; PCOUT = 0x0000;   /* P5, P6 */
    PDDIR = 0xFFFF; PDOUT = 0x0000;   /* P7, P8 */

    PM5CTL0 &= ~LOCKLPM5;
}

#if BRINGUP == 1            /* ---- Task 1: blink LED2 (P4.0) ~1 Hz ---- */

int main(void)
{
    board_init();
    P4DIR |=  BIT0;
    P4OUT &= ~BIT0;
    for (;;) {
        P4OUT ^= BIT0;
        __delay_cycles(500000);   /* ~0.5 s at ~1 MHz default MCLK */
    }
}

#elif BRINGUP == 2          /* ---- Task 2: LCD_E "HELLO" ---- */

#include "hal_lcd.h"

int main(void)
{
    board_init();
    hal_lcd_init();
    hal_lcd_display("HELLO");
    for (;;)
        __delay_cycles(1000000);  /* hold the display; nothing else yet */
}

#elif BRINGUP == 3          /* ---- Task 3: caliper LCD segment scan (V3 board) ---- */

#include "caliper_lcd.h"

int main(void)
{
    board_init();
    caliper_lcd_init();
    caliper_lcd_segment_scan_test();  /* lights each (Lxx,COM) in turn; never returns */
    return 0;
}

#elif BRINGUP == 4          /* ---- Task 4: XT1+RTC timekeeping (LaunchPad) ---- */

#include "hal_lcd.h"
#include "rtc_clock.h"

/* Validates the timekeeping engine on the LaunchPad: time on the FH-1138P glass
 * (HH MM), LED2 toggling at 1 Hz as the "RTC is ticking" heartbeat. The caliper
 * glass + colon/PM integration happens on the V3 board. */
int main(void)
{
    board_init();
    clock_init_xt1();                 /* ACLK <- 32.768 kHz crystal */
    rtc_init();                       /* 1 Hz RTC interrupt */
    hal_lcd_init();
    clock_set(12, 0);                 /* start at 12:00 */

    P4DIR |= BIT0;                    /* LED2 (P4.0) = 1 Hz heartbeat */
    __enable_interrupt();

    /* Disable interrupts to test the flag atomically with entering LPM3, so an
     * RTC tick that fires just before sleep isn't slept through (lost wakeup). */
    for (;;) {
        __disable_interrupt();
        if (clock_tick) {
            uint8_t h12, mn, pm;
            char buf[5];
            clock_tick = 0;
            __enable_interrupt();
            P4OUT ^= BIT0;            /* heartbeat */

            clock_read(&h12, &mn, &pm);
            buf[0] = (h12 >= 10) ? '0' + h12 / 10 : ' ';  /* blank leading zero */
            buf[1] = '0' + h12 % 10;
            buf[2] = '0' + mn / 10;
            buf[3] = '0' + mn % 10;
            buf[4] = '\0';
            hal_lcd_display(buf);
        } else {
            __bis_SR_register(LPM3_bits | GIE);   /* sleep until next RTC tick */
        }
    }
}

#elif BRINGUP == 5          /* ---- Task 5: buttons + LPM3 wake ---- */

#include "hal_lcd.h"
#include "buttons.h"

/* Sleeps in LPM3; a button (P1.0=MODE, P1.1=HOUR, P1.2=MIN, each shorted to GND)
 * wakes the MCU, the press is debounced, its name shows on the glass, and LED2
 * toggles. Proves the button IRQ wakes from LPM3 and debounce works. */
int main(void)
{
    board_init();
    hal_lcd_init();
    buttons_init();
    hal_lcd_display("PUSH");
    P4DIR |= BIT0;
    __enable_interrupt();

    /* Atomic test-and-sleep (see Task 4) so a press just before LPM3 entry is
     * not slept through. buttons_get_event() preserves the (disabled) interrupt
     * state, so it can be called inside the critical section. */
    for (;;) {
        button_t e;
        __disable_interrupt();
        e = buttons_get_event();
        if (e != BTN_NONE) {
            __enable_interrupt();
            P4OUT ^= BIT0;
            switch (e) {
            case BTN_MODE: hal_lcd_display("MODE"); break;
            case BTN_HOUR: hal_lcd_display("HOUR"); break;
            case BTN_MIN:  hal_lcd_display("MIN");  break;
            default: break;
            }
        } else {
            __bis_SR_register(LPM3_bits | GIE);   /* sleep until a button wakes us */
        }
    }
}

#elif BRINGUP == 6          /* ---- Task 6: full clock + set-time UI (LaunchPad) ---- */

#include "hal_lcd.h"
#include "rtc_clock.h"
#include "buttons.h"
#include "clock_app.h"

/* LaunchPad display backend: show " H:MM" style on the FH-1138P glass (no colon
 * segment exposed here, so the set-mode flash is the visual feedback). */
static void launchpad_show(uint8_t h12, uint8_t mn, uint8_t colon, uint8_t pm,
                           uint8_t blank)
{
    char buf[5];
    (void)colon; (void)pm;
    if (blank) { hal_lcd_display("    "); return; }
    buf[0] = (h12 >= 10) ? '0' + h12 / 10 : ' ';
    buf[1] = '0' + h12 % 10;
    buf[2] = '0' + mn / 10;
    buf[3] = '0' + mn % 10;
    buf[4] = '\0';
    hal_lcd_display(buf);
}

int main(void)
{
    board_init();
    clock_init_xt1();
    rtc_init();
    hal_lcd_init();
    buttons_init();
    clock_set(12, 0);
    __enable_interrupt();

    clock_app_run(launchpad_show);    /* never returns */
    return 0;
}

#elif BRINGUP == 7          /* ---- V3 final: full clock on the caliper LCD ---- */

#include "caliper_lcd.h"
#include "rtc_clock.h"
#include "buttons.h"
#include "clock_app.h"

/* V3 display backend: hand the 4-digit value + colon + PM straight to the
 * caliper-LCD driver, which already does V2's leading-zero blanking for the
 * hours. Blank means clear all four digits for the set-mode flash. */
static void caliper_show(uint8_t h12, uint8_t mn, uint8_t colon, uint8_t pm,
                         uint8_t blank)
{
    if (blank) {
        caliper_lcd_clear();
        return;
    }
    caliper_lcd_show_4digit((uint16_t)h12 * 100 + mn, colon, pm);
}

int main(void)
{
    board_init();
    clock_init_xt1();
    rtc_init();
    caliper_lcd_init();               /* the real caliper glass via LCD_E */
    buttons_init();
    clock_set(12, 0);
    __enable_interrupt();

    clock_app_run(caliper_show);      /* never returns */
    return 0;
}

#elif BRINGUP == 8          /* ---- diagnostic: caliper LCD static "8888" ---- */

#include "caliper_lcd.h"

/* Statically display 8888 with colon + PM lit. Every segment of D0/D1/D2 should
 * light (a full 8), plus the b/c/g segments of D3 (the partial digit). If a
 * digit shows fewer or different segments than this, the segment-line map
 * (HT1621_ADDR_TO_LCDE_SEG) is off. If everything looks right here but the
 * BRINGUP=7 clock is gibberish, the COM ordering between V2 and V3 differs. */
int main(void)
{
    board_init();
    caliper_lcd_init();
    caliper_lcd_show_4digit(8888, 1, 1);
    for (;;)
        __delay_cycles(1000000);
}

#elif BRINGUP == 9          /* ---- raw all-on diagnostic ---- */

#include <stdint.h>
#include "caliper_lcd.h"

/* Light every LCD-memory bit for L8..L19 (and re-confirm COM mapping). Bypasses
 * caliper_lcd_set_segment / set_lcde_segment / V2 map entirely -- writes 0xFF to
 * each LCD memory byte by raw pointer. If a (Lxx, COM) physically reaches a
 * working backplane on the caliper LCD, its segment must light here. If a
 * segment is dark in BRINGUP=8 but lights here, the issue is in caliper_lcd's
 * helper path; if it's dark in both, that signal isn't reaching the glass. */
int main(void)
{
    uint8_t i;

    board_init();
    caliper_lcd_init();                 /* same init as BRINGUP=3 and =8 */

    /* Also enable LCD function on L18, L19 (LCDPCTL1 bits 2,3), since they
     * carry LCD_SEG10 and (possibly NC) and aren't enabled by caliper_lcd_init. */
    LCDPCTL1 |= 0x000C;

    /* LCDMEM bytes: 0,1 = COM config (don't touch); 4..9 = L8..L19. Form each
     * byte's address from &LCDM0 in integer arithmetic to dodge GCC's
     * -Warray-bounds false positive on the 1-byte SFR (same trick caliper_lcd.c
     * uses via lcd_byte()). */
    for (i = 4; i <= 9; i++)
        *(volatile uint8_t *)((uintptr_t)&LCDM0 + i) = 0xFF;

    for (;;)
        __delay_cycles(1000000);
}

#elif BRINGUP == 10         /* ---- diagnostic: 8888 + LCDPCTL1 L18/L19 enabled ---- */

#include "caliper_lcd.h"

int main(void)
{
    board_init();
    caliper_lcd_init();
    /* Enable L18 and L19 as LCD pins (LCDPCTL1 bits 2, 3), but do NOT write
     * any data to byte 9 (LCDM9). Then drive 8888 via show_4digit. If this is
     * enough to make the previously-dark segments (PM, colon, D2-a, D1-b/f,
     * D0-a/b/c/f) light, then enabling extra LCDPCTL bits is what mattered in
     * BRINGUP=9, not the byte-9 writes. */
    LCDPCTL1 |= 0x000C;
    caliper_lcd_show_4digit(8888, 1, 1);
    for (;;)
        __delay_cycles(1000000);
}

#elif BRINGUP == 11         /* ---- diagnostic: 8888 + enable + drive L18/L19 ---- */

#include "caliper_lcd.h"
#include <stdint.h>

int main(void)
{
    board_init();
    caliper_lcd_init();
    LCDPCTL1 |= 0x000C;                                    /* enable L18, L19 */
    caliper_lcd_show_4digit(8888, 1, 1);
    *(volatile uint8_t *)((uintptr_t)&LCDM0 + 9) = 0xFF;  /* drive L18/L19 all COMs */
    for (;;)
        __delay_cycles(1000000);
}

#elif BRINGUP == 12         /* ---- diagnostic: like BRINGUP=11 + VLCD_6 ---- */

#include <msp430.h>
#include "caliper_lcd.h"
#include <stdint.h>

int main(void)
{
    board_init();
    caliper_lcd_init();

    /* Re-write LCDVCTL with VLCD_6 added to Mode 2 (LCDCPEN supposedly requires
     * VLCDx > 0 OR VLCDREFx > 0 to actually enable the charge pump, per SLAU445
     * Table 17-14). LCDON must be off while changing LCDVCTL. */
    LCDCTL0 &= ~LCDON;
    LCDVCTL = LCDSELVDD | LCDCPEN | VLCD_6
            | LCDCPFSEL3 | LCDCPFSEL2 | LCDCPFSEL1 | LCDCPFSEL0;
    LCDCTL0 |= LCDON;

    LCDPCTL1 |= 0x000C;                                    /* enable L18, L19 */
    caliper_lcd_show_4digit(8888, 1, 1);
    *(volatile uint8_t *)((uintptr_t)&LCDM0 + 9) = 0xFF;  /* drive L18/L19 */
    for (;;)
        __delay_cycles(1000000);
}

#elif BRINGUP == 13         /* ---- diagnostic: COM-swap test (LCDM0W = 0x1428) ---- */

#include <msp430.h>
#include "caliper_lcd.h"
#include <stdint.h>

int main(void)
{
    board_init();
    caliper_lcd_init();

    /* Swap L0 <-> L3 COM assignment: L0 = COM3, L1 = COM1, L2 = COM2, L3 = COM0.
     * Hypothesis: J1.1 (= L3) is wired to V2's unused COM0 backplane (NC), and
     * J1.2 (= L0) is wired to V2's COM3 backplane. So routing firmware "COM3"
     * phase to L0 makes V2-COM3 segments light when the firmware writes bit 3
     * of the lower nibble (its normal V2-com=3 idiom). LCDON must be off while
     * changing the COM-assignment registers. */
    LCDCTL0 &= ~LCDON;
    LCDM0W  = 0x1428;
    LCDBM0W = 0x1428;
    LCDCTL0 |= LCDON;

    LCDPCTL1 |= 0x000C;                                    /* enable L18, L19 */
    caliper_lcd_show_4digit(8888, 1, 1);
    *(volatile uint8_t *)((uintptr_t)&LCDM0 + 9) = 0xFF;  /* drive L18/L19 */
    for (;;)
        __delay_cycles(1000000);
}

#elif BRINGUP == 14         /* ---- diagnostic: slow (Lxx, COMy) scan ---- */

#include "caliper_lcd.h"

/* Walks every (Lxx, COMy) for 4 s each so you can write down which physical
 * caliper segment lights at each step. Cycle marker = all-on (4 s) + all-dark
 * (4 s), then the 44 positions start in fixed order. The recorded table inverts
 * against V2's DIGIT_SEG to give the V2->V3 (addr,com) translation. */
int main(void)
{
    board_init();
    caliper_lcd_init();                  /* same init as BRINGUP=7/8/13 */
    LCDPCTL1 |= 0x000C;                  /* keep L18 enabled (used for addr 10) */
    caliper_lcd_segment_scan_slow();     /* never returns */
    return 0;
}

#elif BRINGUP == 15         /* ---- diagnostic: static 1200, colon toggled in SW ---- */

#include "caliper_lcd.h"
#include <stdint.h>

/* Show "1200" PM with the colon bit deliberately alternated on/off every 3 s
 * by software (no RTC, no clock_app). If the decimal blinks here, the SEG_COLON
 * write path is correct and any "no-blink" in BRINGUP=7 is upstream (RTC ISR,
 * clock_colon variable, clock_app refresh). If it stays steady (on OR off),
 * then SEG_COLON's (addr, com) isn't actually wired to the dot the eye reads
 * as the decimal -- the scan's "L13 com 3 = colon/decimal" was a misread. */
int main(void)
{
    uint8_t colon = 0;

    board_init();
    caliper_lcd_init();

    for (;;) {
        caliper_lcd_show_4digit(1200, colon, 1);
        __delay_cycles(3000000);          /* ~3 s at ~1 MHz default MCLK */
        colon ^= 1;
    }
}

#elif BRINGUP == 16         /* ---- diagnostic: ONLY SEG_COLON candidate ---- */

#include "caliper_lcd.h"

/* Light ONLY V2 (5, 3) -- the SEG_COLON candidate -- alternating with all
 * segments off, ~4 s per state. No digits, no PM, no other writes. Whatever
 * physical segment appears/disappears in sync is what SEG_COLON drives.
 * Use this to definitively confirm or refute the "L13 com 3 = decimal" call
 * in the BRINGUP=14 scan. */
int main(void)
{
    board_init();
    caliper_lcd_init();

    for (;;) {
        caliper_lcd_clear();
        caliper_lcd_set_segment(5, 3, 1);
        __delay_cycles(4000000);             /* ~4 s lit */
        caliper_lcd_clear();
        __delay_cycles(4000000);             /* ~4 s dark */
    }
}

#elif BRINGUP == 17         /* ---- diagnostic: walk com=3 across V2 addrs ---- */

#include "caliper_lcd.h"
#include <stdint.h>

/* Walk V2 (addr=1..10, com=3), one segment at a time, ~5 s each. Order:
 *   (blank 5 s) -> (1,3) -> (2,3) -> ... -> (10,3) -> (blank 5 s) -> repeat.
 * Notes the addr at which the decimal between D2 and D1 lights, so SEG_COLON
 * can be relabeled to that (addr, 3). */
int main(void)
{
    board_init();
    caliper_lcd_init();

    for (;;) {
        uint8_t addr;
        caliper_lcd_clear();
        __delay_cycles(5000000);             /* ~5 s cycle marker */
        for (addr = 1; addr <= 10; addr++) {
            caliper_lcd_clear();
            caliper_lcd_set_segment(addr, 3, 1);
            __delay_cycles(5000000);
        }
    }
}

#else
#error "Unknown BRINGUP value (expected 1..17)"
#endif

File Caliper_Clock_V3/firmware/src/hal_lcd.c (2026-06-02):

/*
 * hal_lcd.c -- LaunchPad FH-1138P LCD driver (MSP430FR4133 LCD_E). See hal_lcd.h.
 *
 * Provenance (both BSD-3 / verified against the real glass):
 *   - Segment tables + showChar word-write: TI hal_LCD.c, E. Chen, 2014.
 *   - Bare-register Init (no driverlib): Energia LCD_Launchpad (FR4133 path).
 *
 * Register details cite the MSP430FR4xx/FR2xx Family User's Guide (SLAU445,
 * "LCD_E Controller") -- see ../Datasheets/slau445.pdf.
 */

#include <msp430.h>
#include <stdint.h>
#include "hal_lcd.h"

/*
 * Word access to LCD memory. The GCC device header defines
 *   LCDMEM == (volatile char *)&LCDM0
 * i.e. a byte pointer at the base of the LCD memory map, so a word pointer
 * lets us write a whole digit (two adjacent byte-memories) in one access --
 * exactly as TI's hal_LCD does. LCDMEMW[n] is the word at byte offset 2*n.
 * Unsigned so segment math never sign-extends or overflows a signed 16-bit int.
 */
#define LCDMEMW ((volatile unsigned int *)LCDMEM)

/* Pack a {low, high} segment pattern into one 16-bit LCD-memory word.
 * Done in unsigned int to be safe regardless of char signedness and to avoid
 * the signed-overflow UB of `(0xA0 << 8)` on this 16-bit-int target. */
static inline unsigned int seg_word(const uint8_t pat[2])
{
    return (unsigned int)pat[0] | ((unsigned int)pat[1] << 8);
}

/*
 * FH-1138P digit -> LCD-memory byte offset (from TI hal_LCD). Each alphanumeric
 * character A1..A6 is driven by two adjacent byte-memories (one 16-bit word).
 * Index 0 is the leftmost digit (A1). These are NOT sequential because of how
 * the glass is wired to the segment lines.
 */
static const unsigned char lcd_pos[HAL_LCD_NUM_DIGITS] = {
    4,   /* A1 - L4  */
    6,   /* A2 - L6  */
    8,   /* A3 - L8  */
    10,  /* A4 - L10 */
    2,   /* A5 - L2  */
    18   /* A6 - L18 */
};

/* Segment patterns for '0'-'9' (low byte, high byte). From TI hal_LCD. */
static const uint8_t digit[10][2] = {
    {0xFC, 0x28}, {0x60, 0x20}, {0xDB, 0x00}, {0xF3, 0x00}, {0x67, 0x00},
    {0xB7, 0x00}, {0xBF, 0x00}, {0xE4, 0x00}, {0xFF, 0x00}, {0xF7, 0x00}
};

/* Segment patterns for 'A'-'Z'. From TI hal_LCD. */
static const uint8_t alphabetBig[26][2] = {
    {0xEF, 0x00}, {0xF1, 0x50}, {0x9C, 0x00}, {0xF0, 0x50}, {0x9F, 0x00},
    {0x8F, 0x00}, {0xBD, 0x00}, {0x6F, 0x00}, {0x90, 0x50}, {0x78, 0x00},
    {0x0E, 0x22}, {0x1C, 0x00}, {0x6C, 0xA0}, {0x6C, 0x82}, {0xFC, 0x00},
    {0xCF, 0x00}, {0xFC, 0x02}, {0xCF, 0x02}, {0xB7, 0x00}, {0x80, 0x50},
    {0x7C, 0x00}, {0x0C, 0x28}, {0x6C, 0x0A}, {0x00, 0xAA}, {0x00, 0xB0},
    {0x90, 0x28}
};

void hal_lcd_init(void)
{
    LCDCTL0 &= ~LCDON;                 /* turn LCD off while (re)configuring */

    /* Enable the segment-line pins used by the FH-1138P: L0-L26 and L36-L39.
     * (SLAU445 LCDPCTLx: 1 = pin under LCD_E control.) */
    LCDPCTL0 = 0xFFFF;                 /* L0-L15  */
    LCDPCTL1 = 0x07FF;                 /* L16-L26 */
    LCDPCTL2 = 0x00F0;                 /* L36-L39 */

    /* L0-L3 are common (backplane) lines, not segments. */
    LCDCSSEL0 = 0x000F;

    /* 4-mux (LCDMX0|LCDMX1), source = ACLK (LCDSSEL_1; SLAU445 Table 17-10:
     * 00b=XT1CLK, 01b=ACLK, 10b=VLOCLK). Energia uses LCDSSEL_0=XT1CLK because
     * its framework starts XT1 first; we use ACLK so the default REFO (~32 kHz,
     * auto-on when ACLK is requested) drives the LCD with no clock init.
     * Low-power waveform (LCDLP), segments on (LCDSON), divide by 3 (LCDDIV_2). */
    LCDCTL0 = LCDMX0 | LCDMX1 | LCDSSEL_1 | LCDLP | LCDSON | LCDDIV_2;

    /* Charge-pump bias (Mode 3): internal reference enabled (LCDREFEN),
     * charge pump enabled (LCDCPEN), VLCD ~3.0 V (VLCD_6), pump clock freq
     * select bits. This matches the LaunchPad reference config; the V3 board
     * uses the external flying cap (C7) on LCDCAP0/1. SLAU445 "LCDVCTL". */
    LCDVCTL = LCDREFEN | LCDCPEN | VLCD_6
            | LCDCPFSEL3 | LCDCPFSEL2 | LCDCPFSEL1 | LCDCPFSEL0;

    LCDMEMCTL |= LCDCLRM | LCDCLRBM;   /* clear display + blink memory */

    /* Map common lines L0->COM0, L1->COM1, L2->COM2, L3->COM3. The value packs
     * one nibble per pin (0x1,0x2,0x4,0x8). Verified constant from TI/Energia;
     * see SLAU445 LCD memory/COM mapping for the bit layout. */
    LCDM0W  = 0x8421;
    LCDBM0W = 0x8421;

    LCDMEMCTL &= ~LCDDISP;             /* display from main memory (not blink) */

    LCDCTL0 |= LCDON;                  /* turn the LCD on */
}

void hal_lcd_clear(void)
{
    int i;
    for (i = 0; i < HAL_LCD_NUM_DIGITS; i++)
        LCDMEMW[lcd_pos[i] / 2] = 0;
}

void hal_lcd_show_char(char c, int digit_index)
{
    unsigned char pos;

    if (digit_index < 0 || digit_index >= HAL_LCD_NUM_DIGITS)
        return;
    pos = lcd_pos[digit_index];

    if (c == ' ')
        LCDMEMW[pos / 2] = 0;
    else if (c >= '0' && c <= '9')
        LCDMEMW[pos / 2] = seg_word(digit[c - '0']);
    else if (c >= 'A' && c <= 'Z')
        LCDMEMW[pos / 2] = seg_word(alphabetBig[c - 'A']);
    else
        LCDMEMW[pos / 2] = 0xFFFF;     /* unsupported char: all segments on */
}

void hal_lcd_display(const char *s)
{
    int i;
    for (i = 0; i < HAL_LCD_NUM_DIGITS; i++) {
        if (*s) {
            hal_lcd_show_char(*s, i);
            s++;
        } else {
            hal_lcd_show_char(' ', i);   /* pad the rest with blanks */
        }
    }
}

void hal_lcd_scroll(const char *s)
{
    int length = 0;
    int start, i;
    while (s[length])
        length++;

    /* Slide a 6-char window across the message, blank padding on both ends. */
    for (start = HAL_LCD_NUM_DIGITS; start > -length; start--) {
        for (i = 0; i < HAL_LCD_NUM_DIGITS; i++) {
            int idx = i - start;     /* index into s for digit i */
            if (idx >= 0 && idx < length)
                hal_lcd_show_char(s[idx], i);
            else
                hal_lcd_show_char(' ', i);
        }
        __delay_cycles(250000);      /* ~scroll step; default MCLK ~1 MHz */
    }
}

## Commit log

2025-09-08 Initial commit: ESP32 LCD driver and upload tools
    - Add lcd_driver.py: Clean ESP32 bare-glass LCD driver for CaliperClock
    - Add upload_to_esp32.sh: Enhanced upload script with progress indicator
    - Add README.md: Project documentation
2026-01-05 Add complete Caliper Clock project files
    - KiCad PCB designs (V1, V2, Test Board)
    - Gerber files for manufacturing
    - ESP32 firmware source code (main.c and variants)
    - Python LCD driver and screen decoding utilities
    - Makefile for building
    - BOM and position files for assembly
    [Caliper Clock BOM - Sheet1 (4).csv, Caliper Clock BOM - Sheet3 (3).csv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]
2026-05-21 Add Caliper Clock V3 design and MSP430FR4133 symbol library
    Add V3 KiCad project (schematic, PCB, gerbers, placement files), import
    the MSP430FR4133IPM symbol/footprint library, and update V2 board files.
    Ignore KiCad lock files and local Claude config.
    [Caliper_Clock_V2.kicad_pcb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]
2026-05-21 Reorganize repo into Caliper Clock V1/V2/V3 folders
    - Rename Caliper_Clock/ to Caliper_Clock_V1/ and nest the test board inside it
    - Move root firmware/tooling (main*.c, *.py, Makefile, README, etc.) into Caliper_Clock_V2/
    - Move MSP430FR4133IPM symbol library into Caliper_Clock_V3/
    - Update README PCB Designs section to match the new layout
    [Caliper Clock BOM - Sheet1 (4).csv, Caliper Clock BOM - Sheet3 (3).csv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]
2026-05-21 Add V3 firmware skeleton (Task 1: toolchain + blink stub)
    MSP430FR4133 firmware project under Caliper_Clock_V3/firmware/, built with
    MSP430-GCC (MacPorts msp430-elf-gcc) and flashed via mspdebug tilib.
    - Makefile: make/flash/debug/clean/size; SUPPORT_DIR defaults to the verified
    MacPorts path /opt/local/msp430-elf/include; flash target wraps mspdebug with
    DYLD_LIBRARY_PATH for libmsp430.
    - src/main.c: toolchain-verification blink stub (LaunchPad LED2 on P4.0, ~1 Hz).
    Builds clean (58 B). Not the real firmware -- Tasks 2-7 replace it.
    - README.md: MacPorts install/build/flash walkthrough and current status.
    - .gitignore: build/ and bin/.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
    [main.c]
2026-05-21 Add V3 reference datasheets
    MSP430FR4133 (SLAS865), MSP430FR4xx family UG (SLAU445), LCD_E app note
    (SLAA654), TPS61099 boost converter, and HT1621B (V2 LCD driver) datasheets
    under Caliper_Clock_V3/Datasheets/ for firmware reference.
2026-05-21 Add Task 2: LCD_E driver + HELLO on LaunchPad glass
    - src/hal_lcd.c + inc/hal_lcd.h: FH-1138P driver via LCD_E (4-mux, internal
    charge pump, ACLK), bare registers (no driverlib). Segment tables + showChar
    adapted from TI hal_LCD.c (BSD-3); register init from Energia LCD_Launchpad.
    Relies on default ~32 kHz ACLK; XT1 crystal setup deferred to Task 4 (RTC).
    - Segment-word packing uses uint8_t tables + unsigned math (seg_word), so it's
    correct regardless of char signedness and avoids signed-shift overflow UB on
    this 16-bit-int target.
    - main.c: compile-time BRINGUP selector so each layer is a flashable test
    (1=blink, 2=LCD HELLO). Makefile passes -DBRINGUP; default 2.
    - README: "Bri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
    [hal_lcd.c, main.c]
2026-05-21 Add SLAU595 LaunchPad User's Guide to datasheets
    MSP-EXP430FR4133 LaunchPad UG -- documents the onboard LEDs (LED1=P1.0,
    LED2=P4.0) and the FH-1138P LCD segment mapping used to verify Task 2.
2026-05-21 Add Task 3: caliper LCD driver + segment scan test
    - src/caliper_lcd.c + inc/caliper_lcd.h: drives the actual caliper glass on the
    V3 board via LCD_E. V2's segment map (DIGIT_SEG/DIGIT_PATTERN/colon/PM) ported
    verbatim -- the trusted, experimentally-derived glass data.
    - The only unverified piece (V2 HT1621 address -> V3 LCD_E segment line) is
    isolated in one flagged table, HT1621_ADDR_TO_LCDE_SEG[], resolved on hardware
    via caliper_lcd_segment_scan_test() (BRINGUP=3).
    - LCD_E config: 4-mux, COMs on L0-L3, segments on L8-L17, Mode 2 bias (VLCD from
    VDD + charge pump + flying cap) -- datasheet-verified against SLAU445 §17.2.8.1
    and §17.2.3.2.1. lcd_byte() addresses LCD memory vi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
    [main.c]
2026-05-21 Add Task 4: XT1 + RTC timekeeping
    - src/rtc_clock.c + inc/rtc_clock.h: source ACLK from the 32.768 kHz XT1 crystal
    and run the RTC counter at 1 Hz, maintaining sec/min/hour24 with 24->12
    conversion ported from V2. Board-independent (MCU-internal).
    - Register choices datasheet-verified: XT1 enable via P4SEL0 bits 1/2 (datasheet
    Table 9-18), CS clock select/fault handling (SLAU445 ch.3), RTC counter
    source/predivide/modulo for 1 Hz (SLAU445 ch.15): RTCPS__1024 gives 32 Hz and
    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
2026-05-21 Add Task 5: buttons + LPM3 wake
    - src/buttons.c + inc/buttons.h: P1.0/1.1/1.2 = MODE/HOUR/MIN, internal pull-ups,
    active-low falling-edge interrupts that wake the MCU from LPM3, with a 50 ms
    Timer_A0 (ACLK) debounce -- first edge latches the press, further edges ignored
    for the window. buttons_get_event() + buttons_is_down() (latter for Task 6
    hold/long-press). Register choices per SLAU445 Digital I/O + Timer_A chapters.
    - main.c: BRINGUP=5 sleeps in LPM3 and shows the pressed button on the glass.
    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
2026-05-21 Add Task 6 (set-time UI) and Task 7 (low-power init + profiling guide)
    Task 6 -- src/clock_app.c + inc/clock_app.h:
    - Display + time-setting state machine ported from V2's time_setting_mode:
    5 s MODE long-press enters set mode; HOUR/MIN adjust with hold-to-repeat
    (step once, then auto-repeat after ~400 ms); digits flash ~100 ms every
    ~700 ms; short MODE press commits to the RTC via clock_set().
    - Display abstracted behind a callback so the same logic runs on the LaunchPad
    (FH-1138P) and the V3 caliper glass. Timer_A1 = 20 ms UI tick, running only
    during an interaction (idles in LPM3 otherwise).
    - main.c: BRINGUP=6 runs the full clock on the LaunchPad.
    Task 7 -- low-power init + pr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
    [main.c]
2026-05-21 Bug-review fixes, comments, README, and add CLAUDE.md
    Deep bug review (with an independent reviewer). Fixes:
    - Lost-wakeup race (critical): the test-then-sleep in the Task 4/5 main loops and
    clock_app_run could sleep through an RTC tick or button press. Now uses the
    atomic pattern: __disable_interrupt(), test the pending work, and either handle
    it or __bis_SR_register(LPM3_bits|GIE) which enters LPM3 and sets GIE atomically.
    - Set-mode auto-repeat (major): held HOUR/MIN stepped every 20 ms (50/s) once past
    the threshold. Added hold_step() -> initial step, then ~120 ms repeats.
    - clock_set (minor): now issues RTCSR and clears a pending flag so a freshly set
    time starts a full second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
    [main.c]
2026-05-21 Makefile: track header dependencies (-MMD -MP)
    Object files depended only on their .c, so editing a header (e.g. inc/*.h) left
    stale binaries. Add -MMD -MP and -include build/*.d so header edits trigger the
    right rebuilds. Also refresh the BRINGUP comment (now 1..6).
2026-06-01 Fix LCDSSEL in hal_lcd and caliper_lcd (LCDSSEL_0 != ACLK)
    SLAU445 Table 17-10: LCDSSEL_0 = XT1CLK, LCDSSEL_1 = ACLK, LCDSSEL_2 = VLOCLK.
    Energia's FR4133 LCD_Launchpad uses LCDSSEL_0 (XT1) because its core framework
    starts XT1 before user code; in standalone bring-up code (Task 2/3) XT1 isn't
    running yet, so the LCD had no source clock -- glass was silently blank on
    hardware. Confirmed by flashing BRINGUP=2: HELLO now displays.
    Switch both LCD modules to LCDSSEL_1 (ACLK) so the default REFO (~32 kHz,
    auto-on when ACLK is requested) clocks the LCD. Tasks 4+ already start XT1 and
    move ACLK to it, so behaviour there is unchanged.
    Also: lesson added to CLAUDE.md and project memory -- when por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
    [hal_lcd.c]
2026-06-01 RTC: RTCMOD = 31 (hardware-verified +1 period convention)
    The FR4133 RTC counter overflow convention turns out to match Timer_A up mode
    after all -- period = RTCMOD+1 ticks -- not RTCMOD ticks as SLAU445 §15.2.1's
    "reaches RTCMOD then resets" wording suggested. Confirmed empirically on the
    LaunchPad: RTCMOD=32 produced ~1.03 s heartbeats (~3% slow); RTCMOD=31 ticks at
    the expected 1.000 s. Reviewer hypothesis was right; my datasheet read wasn't.
    Updated CLAUDE.md and project memory with the corrected value and the lesson
    that the silicon is the arbiter when prose is ambiguous.
2026-06-02 V3 caliper LCD bring-up: hardware-verified wiring, diagnostics, contrast fix
    V2's DIGIT_SEG, SEG_COLON=(8,3), SEG_PM=(3,3) all carry over unchanged --
    same physical glass. Two translation fixes + a contrast bump were needed:
    - HT1621_ADDR_TO_LCDE_SEG: V2 addr N -> V3 L(N+8) for N=1..10 (was off-by-one
    to L(N+7); L17 is NOT NC, it carries V2 addr 9 = D0 d/f/g).
    - LCDM0W = 0x1248: L0<->L3 AND L1<->L2 swapped vs. the default. The L1<->L2
    swap is what BRINGUP=13 (only L0<->L3) was missing -- V2 com 1 and com 2
    both need swapping on this board, not just com 3 via L0<->L3.
    - LCDVCTL: LCDCPFSELx = 0 (fastest charge pump) for adequate contrast on this
    glass. Initial all-1s (slowest, lowest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
    [main.c]
2026-06-09 hw: fix boost inductor rail; re-route and regen fab outputs
    Fix the inductor (L1) wiring on the TPS61099 boost: it was tied to
    +3V0 (VOUT) instead of +BATT (VIN), so there was no inductor path from
    the cell into SW and the +3V0 rail stayed dead. Schematic now ties L1 to
    +BATT. This was the root cause of the dead / 0.1 V rail (bench-confirmed
    by jumpering L1 to +BATT, which brought +3V0 up to 3.0 V).
    Re-route the PCB for the corrected net and regenerate Gerbers2/ + BOM/CPL
    for the next fab spin.
    [Caliper_Clock_V3-B_Cu.gbr, Caliper_Clock_V3-B_Mask.gbr, Caliper_Clock_V3-B_Paste.gbr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]
2026-06-09 fw: make v1.0 product the default build; add READMEs
    Makefile: default to BRINGUP=7 (the v1.0 product — full clock on the
    caliper glass with buttons), add FW_VERSION and a build banner so the
    product vs. a diagnostic build is obvious. Numbered bring-up/diagnostic
    builds stay selectable via `make BRINGUP=N`.
    Docs: update the firmware README to reflect the default product build and
    the on-board verification status, and add a concise top-level repo README.
